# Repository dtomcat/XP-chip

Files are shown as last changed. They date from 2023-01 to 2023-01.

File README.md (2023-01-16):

# OpenXenium JTAG and Flash Memory Chip programmer

**This is based on work done by [kooscode](https://github.com/kooscode/xenium-programmer) and [Ryzee119](https://github.com/ryzee119/openxenium) with modifications to program the bare ICs.  Most of the code here was done by kooscode (please visit the link above).

--------------

## * Read: ["Home Brew" on ORIGINAL XBOX](XBOX.md) - a detailed article on why and how *

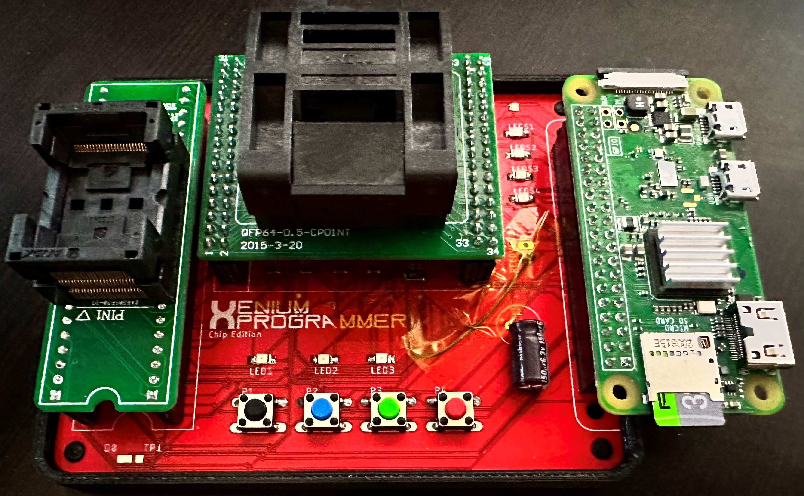
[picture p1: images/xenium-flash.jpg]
xenium-programmer


The tools in this repo will allow you to use a Raspberry PI to program the CPLD and Flash Memory chips of the OpenXenium via Jtag and a custom 4-bit bus NOR Flash programming protocol.
Original project mentioned above allowed the use of an Onion Omega2+... This has been removed for this project. 

### Raspberry PI:
- This has only been tested on PI Zero W and PI 3B+ models so far.

https://www.pishop.us/product/raspberry-pi-zero-w/

-------------
## INSTALLING THE XENIUM PROGRAMMER

- After the OS has been written to your SD card, insert SD card into PC.
    - Add the following to the last line in "config.txt":   `enable_uart=1`
        - This is required to allow the PWR LED to function properly.
- Save edit and eject SD Card.  Insert SD card into Pi and boot up.
- Connect to the PI via SSH or Serial terminal
- If git is not installed, you need to install it:
    - `sudo apt-get install git`
- Clone this repo by running: `git clone https://github.com/dtomcat/XP-chip.git`
- Change to program directory: `cd XP-chip`
- Fix permission on install file:  `chmod 755 install`
- Then run: `./install`
- Setup service to listen for button presses:
    - `sudo cp xeniumCHIP.service /etc/systemd/system/xeniumCHIP.service`
    - `sudo systemctl daemon-reload`
    - `sudo systemctl enable xeniumCHIP`
    - `sudo service xeniumCHIP start`

## UPDATING XENIUM PROGRAMMER

- Connect to the PI via SSH or Serial terminal 
- Pull the latest code with: `git pull`
- Then run: `./install` 

-------------
## PROGRAMMING THE XENIUM CPLD AND/OR FLASH MEMORY (STANDALONE)

- After the PI has fully booted and the green led is on...
    - Press the FIRST button to program both ICs. (both ICs must be inserted into their respective sockets)
    - Hold the FIRST button to program the CPLD with the Bit Bang firmware. (Only the CPLD must be inserted, Flash is optional)
    - Press the SECOND button to program the flash chip. (**The CPLD must be present and have the Bit Bang firmware loaded or this will fail.  Both Chips must be inserted)
    - Press the THIRD button to program the CPLD with the OpenXenium Firmware. (Only the CPLD must be inserted, Flash is optional)
    - Press the FOURTH button to clear any errors.
    - Hold the FOURTH button to shutdown the Raspberry Pi.

-------------
## PROGRAMMING THE XENIUM CPLD AND/OR FLASH MEMORY (SSH/SERIAL)
This is good to do if you keep getting an error trying to program the chips. (Red LED remains on)

- Connect to the PI via SSH or Serial terminal
- Change dir to XP-chip
- You can program CPLD and FLASH in one single step. (Both must be inserted into their respective sockets)
    - Run: `./xenium-programmer-smd`
- You can program just the CPLD in one two ways. (Only the CPLD needs to be inserted into it's socket)
    - To program the Bit Bang firmware: 
        - Run: `./BitBangOnly`
    - To program the OpenXenium firmware: 
        - Run: `./OX-Only_SMD`
- You can program just the Flash. (Both must be inserted into their respective sockets, and the CPLD MUST have the Bit Bang Firmware loaded)
    - Run: `./FlashOnly`

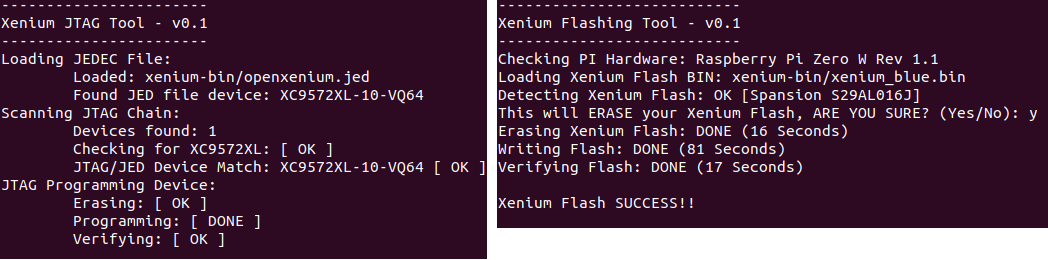
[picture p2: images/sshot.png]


-------------

### PC BOARD

Huge thanks to James Bolding for the Original Eagle PCB hardware design!
This PCB design is based on his original work and the work of Ryzee119's OpenXenium.  

- You can use the FREE Eagle PCB to load this up or just use the gerber files to have the PCB made at OSH Park!

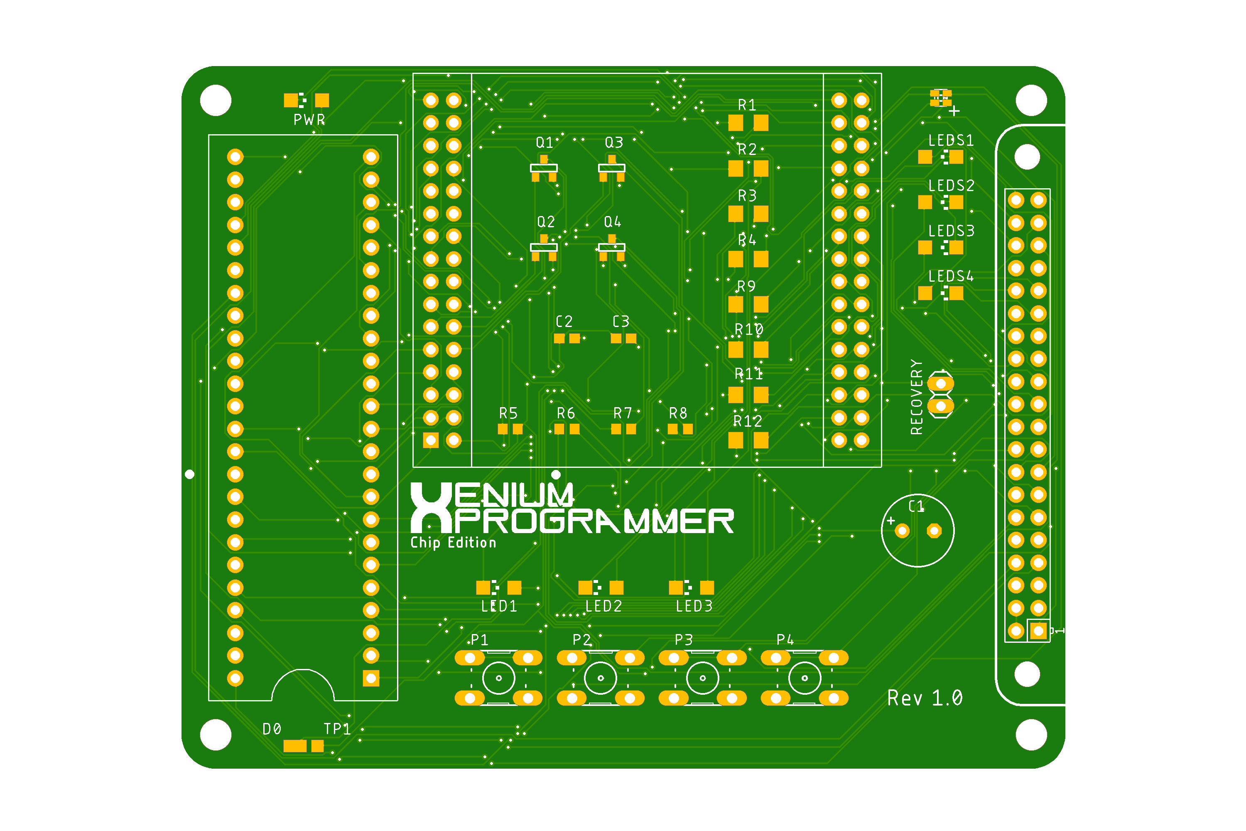
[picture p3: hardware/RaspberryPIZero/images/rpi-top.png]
RPI PXB


--------------

### PARTS NOT LISTED IN BOM
The two sockets were sourced from Ebay (linked below).  They may be available from another source, but the design is based off these particular sockets.  If you decide to go with another source, they may not line up/work.

- CPLD Socket: [QFP64 TQFP64 to DIP64 Pitch 0.5mm IC Programmer Adapter Test Socket](https://www.ebay.com/itm/172825294343)
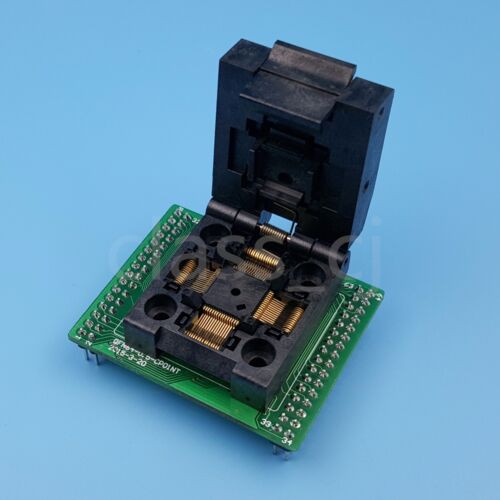
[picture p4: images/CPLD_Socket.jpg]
    
- Flash Socket: [TSOP48 To DIP48 Double Contact Gold Plating Universal IC Programm Socket Adapter](https://www.ebay.com/itm/402764448631)
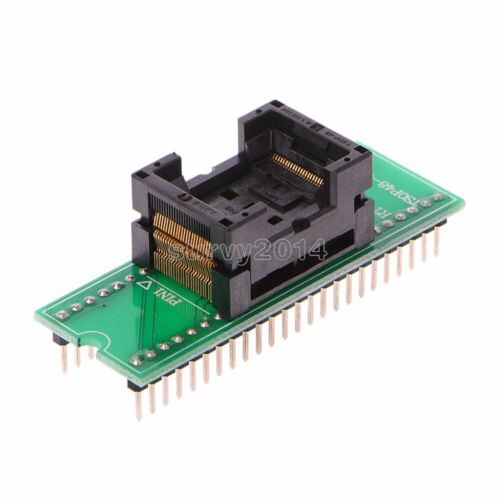
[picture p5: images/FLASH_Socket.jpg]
    

-------------
## CREDITS

- Koos du Preez - Creator (kdupreez@hotmail.com - Comments, improvements, critique, etc. is welcome!)
- Dtomcat - CHIP programmer PCB design.
- James Bolding - Orignal hardware design and PCB!
- Ryzee119 -  OpenXenium Firmware and hardware and all round awesomeness!
- XC3SPROG - Not sure who to thank here, but the source code was pivotal in making this work!

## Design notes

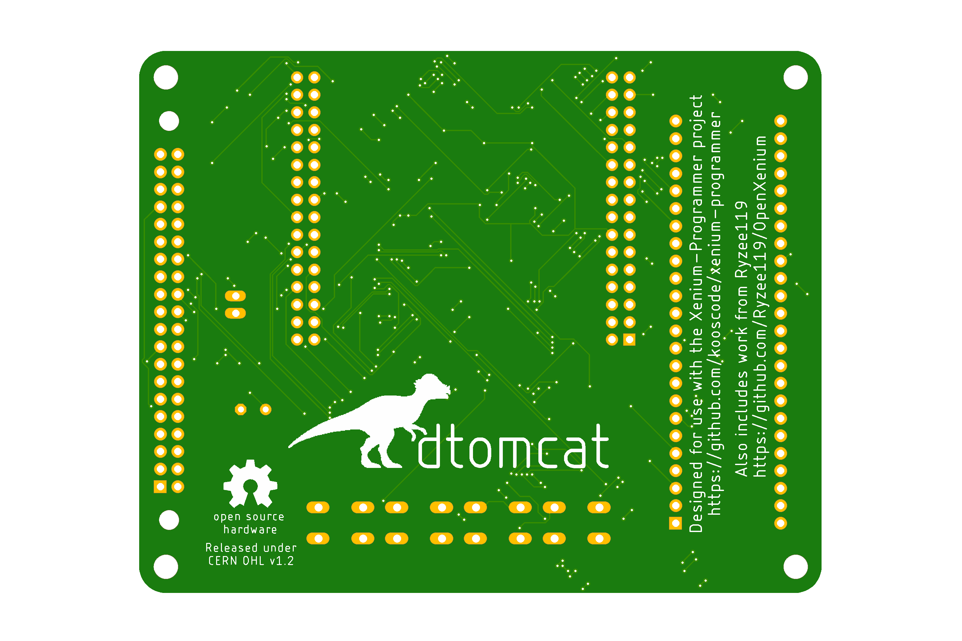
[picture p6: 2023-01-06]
hardware/RaspberryPIZero/images/rpi-bottom.png

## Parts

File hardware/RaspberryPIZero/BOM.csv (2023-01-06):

Reference | Qty | Description | Part Number | Manufacturer | Digikey
R1,R2,R3,R9,R10,R11,R12 | 7 | RES 68 OHM 1% 1/4W 1206 | RC1206FR-1068RL | YAGEO | 13-RC1206FR-1068RLCT-ND
R4 | 1 | RES 15 OHM 1% 1/4W 1206 | RC1206FR-1015RL | YAGEO | 13-RC1206FR-1015RLCT-ND
R5 | 1 | RES 1K OHM 5% 1/10W 0603 | RMCF0603JJ1K00 | Stackpole Electronics Inc | RMCF0603JJ1K00CT-ND
R6,R7,R8 | 3 | RES 68 OHM 5% 1/8W 0603 | RK73B1JTTD680J | KOA Speer Electronics, Inc. | 2019-RK73B1JTTD680JCT-ND
PWR | 1 | LED BLUE CLEAR 1206 SMD | LTST-C150TBKT | Lite-On Inc. | 160-1643-1-ND
LED1 | 1 | LED GREEN CLEAR 1206 SMD | LTST-C150KGKT | Lite-On Inc. | 160-1404-1-ND
LED2 | 1 | LED YELLOW CLEAR 1206 SMD | LTST-C150KSKT | Lite-On Inc. | 160-1406-1-ND
LED3 | 1 | LED RED CLEAR 1206 SMD | LTST-C150KRKT | Lite-On Inc. | 160-1405-1-ND
LEDS1,LEDS2,LEDS3,LEDS4 | 4 | LED ORANGE CLEAR 1206 SMD | LTST-C150KFKT | Lite-On Inc. | 160-1403-1-ND
C1 | 1 | CAP ALUM 150UF 20% 6.3V RADIAL | UPW0J151MED | Nichicon | 493-1698-ND
C2,C3 | 2 | CAP CER 0.1UF 50V X7R 0603 | CL10B104KB8NNNC | Samsung Electro-Mechanics | 1276-1000-1-ND
Q1,Q2,Q3,Q4 | 4 | MOSFET N-CH 20V 4.1A SOT23 | IRLML6246TRPBF | Infineon Technologies | IRLML6246TRPBFCT-ND
RGB | 1 | LED RGB CLEAR 4SMD | 19-237/R6GHBHC-A07/2T | Everlight Electronics Co Ltd | 1080-1590-1-ND
P1,P2,P3,P4 | 4 | SWITCH TACTILE SPST-NO 0.05A 24V | 1825910-6 | TE Connectivity ALCOSWITCH Switches | 450-1650-ND
RPI-CONN | 1 | CONN HDR 40POS 0.1 TIN PCB | PPTC202LFBN-RC | Sullins Connector Solutions | S6104-ND
CPLD-CONN | 2 | CONN HDR 32POS 0.1 TIN PCB | PPTC162LFBN-RC | Sullins Connector Solutions | S7084-ND
FLASH-CONN | 2 | CONN HDR 24POS 0.1 TIN PCB | PPTC241LFBN-RC | Sullins Connector Solutions | S7022-ND

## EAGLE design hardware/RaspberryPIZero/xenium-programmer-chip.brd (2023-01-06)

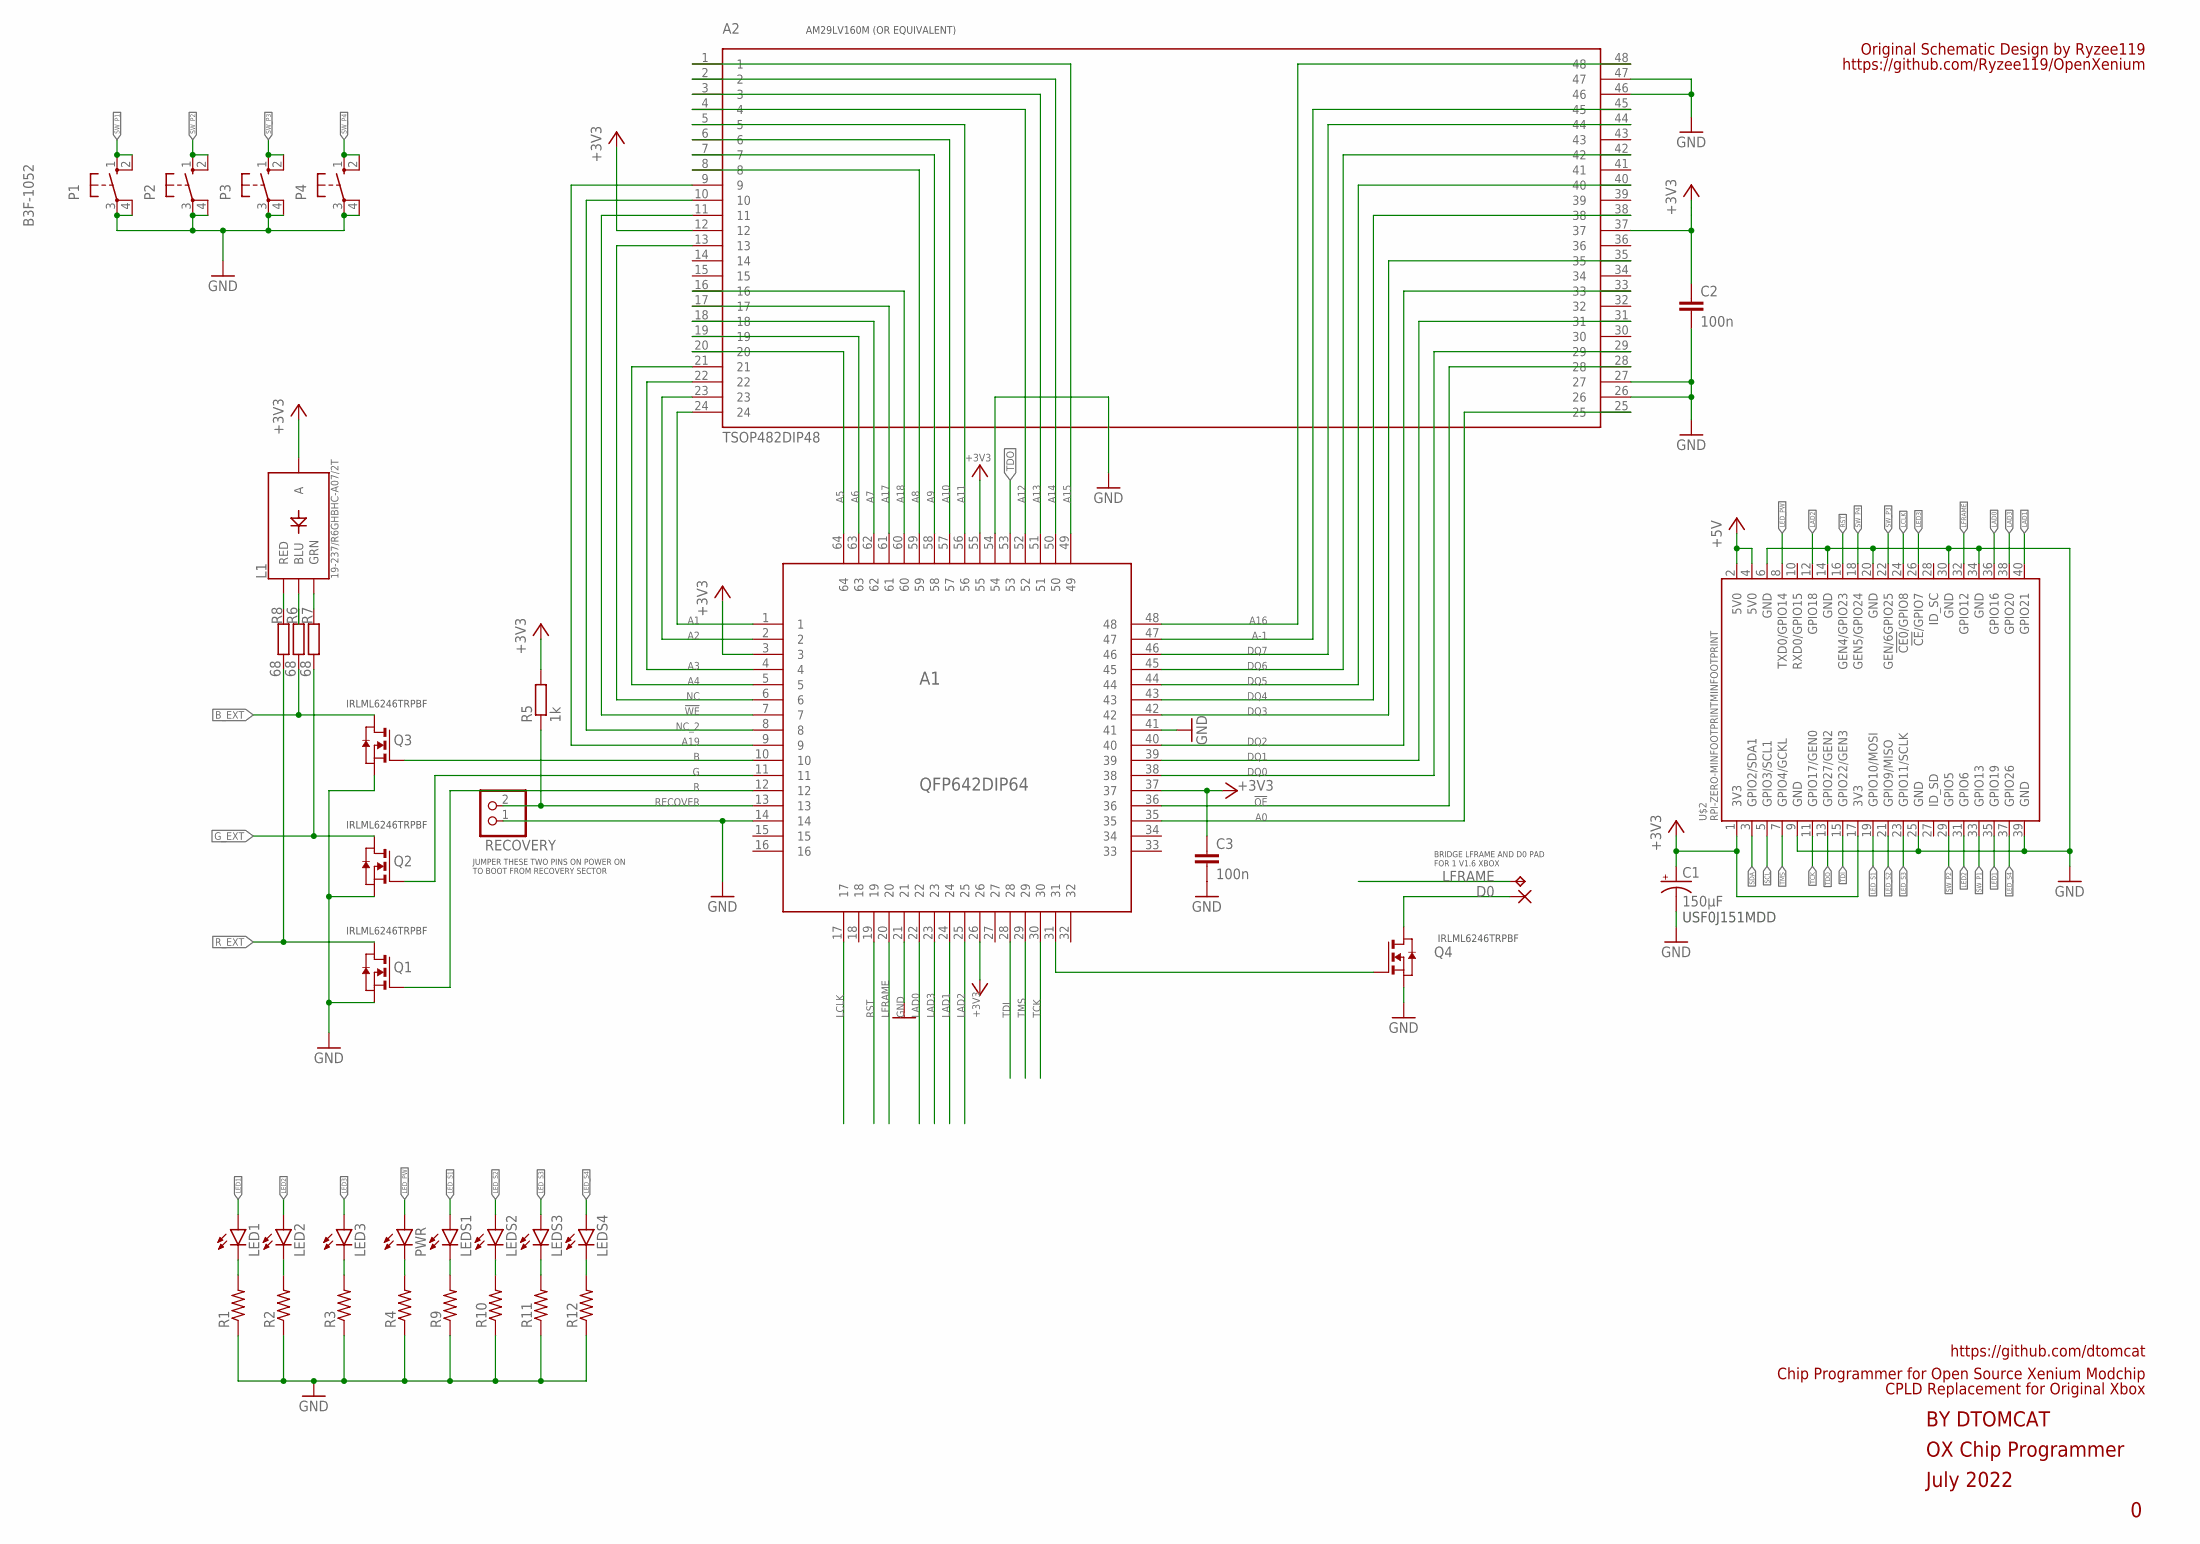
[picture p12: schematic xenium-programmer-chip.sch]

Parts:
A1: QFP642DIP64
A2: TSOP482DIP48
C1: 150µF; E3,5-8
C2, C3: 100n; C0603
D0: SMD2; SMD1,27-2,54
L1: 19-237/R6GHBHC-A07/2T; 4-SMD-R6GHBHC
LED1, LED2, LED3: LEDCHIPLED_1206; CHIPLED_1206
LEDS1, LEDS2, LEDS3, LEDS4: LEDCHIPLED_1206; CHIPLED_1206
P1, P2, P3, P4: B3F-1052; B3F-10XX
PWR: LEDCHIPLED_1206; CHIPLED_1206
Q1, Q2, Q3, Q4: 310mA/60V/1.6Ω; SOT-23
R1, R2, R3, R4, R9, R10, R11, R12: R-US_R1206; R1206
R5: 1k; R0603
R6, R7, R8: 68; R0603
RECOVERY: PINHD-1X2; 1X02
TP1: TPTP13SQ; TP13SQ
U$2: RPI-ZERO-MINFOOTPRINTMINFOOTPRINT; RASP_PI_ZERO_MIN

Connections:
5V0@2: U$2.2 (5V0), U$2.4 (5V0)
!OE: A1.36, A2.28
!WE: A1.7, A2.11
+3V3: A1.3, A1.26, A1.37, A1.55, A2.12, A2.37, C1.+, C2.1, C3.1, L1.P$2 (A), R5.2, U$2.1 (3V3), U$2.17 (3V3)
A0: A1.35, A2.25
A1: A1.1, A2.24
A2: A1.2, A2.23
A3: A1.4, A2.22
A4: A1.5, A2.21
A5: A1.64, A2.20
A6: A1.63, A2.19
A7: A1.62, A2.18
A8: A1.59, A2.8
A9: A1.58, A2.7
A10: A1.57, A2.6
A11: A1.56, A2.5
A12: A1.52, A2.4
A13: A1.51, A2.3
A14: A1.50, A2.2
A15: A1.49, A2.1
A16: A1.48, A2.48
A17: A1.61, A2.17
A18: A1.60, A2.16
A19: A1.9, A2.9
A-1: A1.47, A2.45
B: A1.10, Q3.3 (G)
BLUE: L1.P$4 (BLU), R6.1
B_EXT: Q3.1 (D), R6.2
DQ0: A1.38, A2.29
DQ1: A1.39, A2.31
DQ2: A1.40, A2.33
DQ3: A1.42, A2.35
DQ4: A1.43, A2.38
DQ5: A1.44, A2.40
DQ6: A1.45, A2.42
DQ7: A1.46, A2.44
G: A1.11, Q2.3 (G)
GND: A1.14, A1.21, A1.41, A1.54, A2.26, A2.27, A2.46, A2.47, C1.-, C2.2, C3.2, P1.3, P1.4 (P1), P2.3, P2.4 (P1), P3.3, P3.4 (P1), P4.3, P4.4 (P1), Q1.2 (S), Q2.2 (S), Q3.2 (S), Q4.2 (S), R1.1, R2.1, R3.1, R4.1, R9.1, R10.1, R11.1, R12.1, RECOVERY.1, U$2.6 (GND), U$2.9 (GND), U$2.14 (GND), U$2.20 (GND), U$2.25 (GND), U$2.30 (GND), U$2.34 (GND), U$2.39 (GND)
GREEN: L1.P$3 (GRN), R7.1
G_EXT: Q2.1 (D), R7.2
LAD0: A1.22, U$2.36 (GPIO16)
LAD1: A1.24, U$2.40 (GPIO21)
LAD2: A1.25, U$2.12 (GPIO18)
LAD3: A1.23, U$2.38 (GPIO20)
LCLK: A1.17, U$2.24 (!CE0!/GPIO8)
LED1: LED1.A, U$2.35 (GPIO19)
LED2: LED2.A, U$2.31 (GPIO6)
LED3: LED3.A, U$2.26 (!CE!/GPIO7)
LED_PW: PWR.A, U$2.8 (TXD0/GPIO14)
LED_S1: LEDS1.A, U$2.19 (GPIO10/MOSI)
LED_S2: LEDS2.A, U$2.21 (GPIO9/MISO)
LED_S3: LEDS3.A, U$2.23 (GPIO11/SCLK)
LED_S4: LEDS4.A, U$2.37 (GPIO26)
LFRAME: A1.20, TP1.TP, U$2.32 (GPIO12)
unnamed: LED1.C, R1.2
unnamed: LEDS1.C, R9.2
unnamed: LED2.C, R2.2
unnamed: LED3.C, R3.2
unnamed: PWR.C, R4.2
unnamed: LEDS2.C, R10.2
unnamed: LEDS3.C, R11.2
unnamed: LEDS4.C, R12.2
unnamed: A1.31, Q4.3 (G)
unnamed: D0.1, Q4.1 (D)
NC: A1.6, A2.13
NC_2: A1.8, A2.10
R: A1.12, Q1.3 (G)
RECOVER: A1.13, R5.1, RECOVERY.2
RED: L1.P$1 (RED), R8.1
RST: A1.19, U$2.16 (GEN4/GPIO23)
R_EXT: Q1.1 (D), R8.2
SCL: U$2.5 (GPIO3/SCL1)
SDA: U$2.3 (GPIO2/SDA1)
SW_P1: P1.1 (S), P1.2 (S1), U$2.33 (GPIO13)
SW_P2: P2.1 (S), P2.2 (S1), U$2.29 (GPIO5)
SW_P3: P3.1 (S), P3.2 (S1), U$2.22 (GEN/6GPIO25)
SW_P4: P4.1 (S), P4.2 (S1), U$2.18 (GEN5/GPIO24)
TCK: A1.30, U$2.11 (GPIO17/GEN0)
TDI: A1.28, U$2.15 (GPIO22/GEN3)
TDO: A1.53, U$2.13 (GPIO27/GEN2)
TMS: A1.29, U$2.7 (GPIO4/GCKL)

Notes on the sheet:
OX Chip Programmer
July 2022
BY DTOMCAT
Chip Programmer for Open Source Xenium Modchip
https://github.com/dtomcat
BRIDGE LFRAME AND D0 PAD FOR 1 V1.6 XBOX
JUMPER THESE TWO PINS ON POWER ON TO BOOT FROM RECOVERY SECTOR
IRLML6246TRPBF
AM29LV160M (OR EQUIVALENT)
CPLD Replacement for Original Xbox
Original Schematic Design by Ryzee119
https://github.com/Ryzee119/OpenXenium
USF0J151MDD

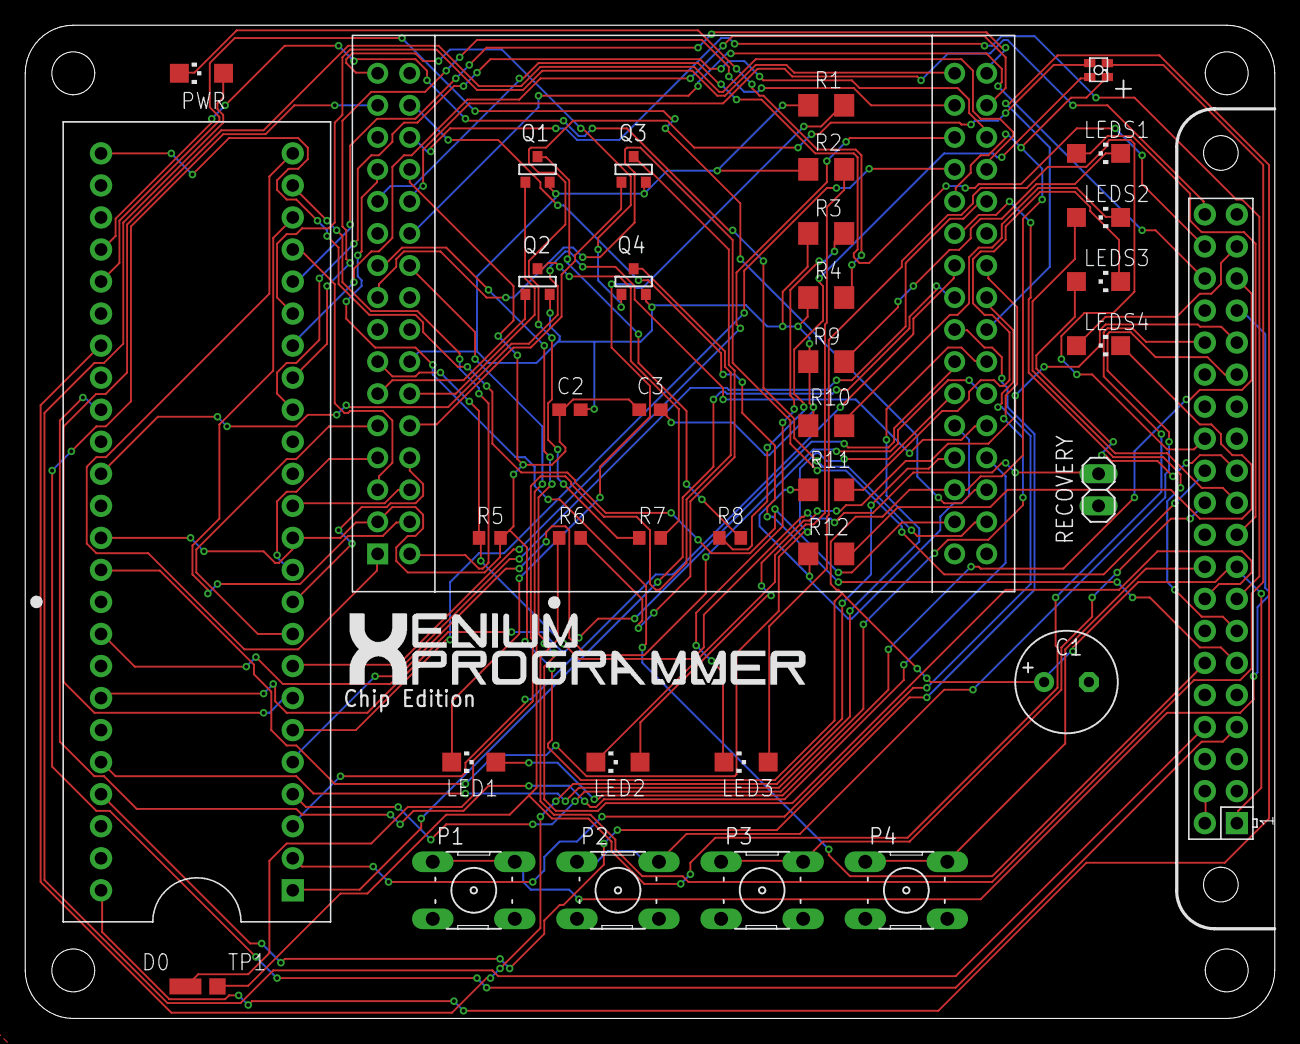
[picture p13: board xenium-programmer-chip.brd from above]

Board: 2 copper layers, 99.1 x 78.7 mm, 39 parts (1 on the bottom side), 79 nets.

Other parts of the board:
U$1: OSHW_8MM

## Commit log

2023-01-06 update Readme for current project and add hardware/images
    [BOM.csv, xenium-programmer-chip.brd, xenium-programmer-chip.sch]
2023-01-16 update for new OS (compatible wiringpi)
2023-01-16 Fix button functions
2026-01-09 Update install
    Updated to fix wiringpi issues since drogon.net took it down.

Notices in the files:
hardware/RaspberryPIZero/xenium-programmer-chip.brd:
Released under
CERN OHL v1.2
